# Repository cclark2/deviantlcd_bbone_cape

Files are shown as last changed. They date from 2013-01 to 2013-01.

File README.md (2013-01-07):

DeviantLCD BeagleBone Cape
==========================

Stick it to standards and bit-bang an LCD interface! This cape features a 240x320 LCD with touchscreen connected to the BeagleBone PRU and GPIOs. Use it when you can't spare the BeagleBone's LCD interface pins for a regular display cape.

Special thanks to <a href="http://www.sparkfun.com/">SparkFun</a> for use of their open-source EAGLE libraries.

## Project Links
- <a href="http://www.hitchhikeree.org/beaglebone_capes/deviantlcd/">HitchhikerEE page</a>
- <a href="http://www.youtube.com/watch?v=hFeXr79dWaM">YouTube video</a>
- <a href="https://docs.google.com/folder/d/0B5HjtPsFD8u5RnRneGhOc2xUcGM/edit">Design files on Google Drive</a>
- <a href="http://beagleboard.org/CapeContest/entries/DeviantLCD/">BeagleBone Cape Contest page</a>

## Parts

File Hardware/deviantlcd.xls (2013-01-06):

Qty | Value | Device | Package | Parts | Description | MPN | Price | Total
1 |  | CAT24C256 | SOIC8 | U$1 |  | CAT24C256WI-GT3 | $0.65 | $0.65
1 |  | FE05-2 | FE05-2 | P6 | FEMALE HEADER | TSHC-105-D-03-255-GT-LF | 0.26 | 0.26
1 |  | FE13-2 | FE13-2 | SV1 | FEMALE HEADER | NPTC132KFMS-RC | 2.76 | 2.76
2 |  | FE23-2 | FE23-2 | P8, P9 | FEMALE HEADER | TSHC-123-D-03-255-GT-LF | 0.97 | 1.94
3 |  | HOLE | HOLE | H1, H3, H4 |  |  |  | 0
1 |  | LP3985 | SOT23-5 | U$10 |  | LP3985IM5-2.8/NOPB | 0.38 | 0.38
1 |  | NHD-2.4-240320SF-CTXI | NHD-2.4-240320SF-CTXI | U$4 |  | NHD-2.4-240320SF-CTXI#-T1 | 22.08 | 22.08
2 |  | SN74LVC1T45 | SOT23-6 | U$7, U$8 |  | SN74LVC1T45DBVR | 0.53 | 1.06
1 |  | SN74LVCH16T245 | TSSOP48 | U$3 |  | SN74LVCH16T245DGGR | 2.16 | 2.16
4 | 0 | R-US_R0402 | R0402 | R44, R49, R50, R51 | RESISTOR, American symbol | ERJ-2GE0R00X | 0.07 | 0.28
4 | 0,DNI | R-US_R0402 | R0402 | R43, R52, R53, R54 | RESISTOR, American symbol | ERJ-2GE0R00X | 0.07 | 0.28
10 | 0.1u | C-EUC0603 | C0603 | C1, C2, C3, C4, C5, C7, C8, C9, C10, C11 | CAPACITOR, European symbol | VJ0603V104ZXXCW1BC | 0.06 | 0.6
1 | 10K | R-US_R0402 | R0402 | R42 | RESISTOR, American symbol | WR06X1002FTL | 0.02 | 0.02
1 | 10K | R-US_R0603 | R0603 | R9 | RESISTOR, American symbol | WR06X1002FTL | 0.02 | 0.02
1 | 10n | C-EUC0603 | C0603 | C18 | CAPACITOR, European symbol | VJ0603Y103KXACW1BC | 0.06 | 0.06
1 | 10u | C-EUC0603 | C0603 | C6 | CAPACITOR, European symbol | LMK107BBJ106MALT | 0.64 | 0.64
5 | 150 | R-US_R0603 | R0603 | R33, R45, R46, R47, R48 | RESISTOR, American symbol | 302-150-RC | 0.04 | 0.2
2 | 1u | C-EUC0603 | C0603 | C17, C19 | CAPACITOR, European symbol | C1608X7R1C105K | 0.07 | 0.14
1 | 219-02 | 219-02 | CTS-219-02 | S1 | Surface Mount DIP Switch Series 219 SMT | 219-2MST | 0.58 | 0.58
30 | 33 | R-US_R0402 | R0402 | R8, R10, R11, R12, R13, R15, R16, R17, R18, R19, R21, R22, R23, R24, R26, R27, R28, R29, R30, R32, R35, R36, R37, R38, R39, R40, R41, R56, R57, R58 | RESISTOR, American symbol | CR0402-JW-330GLF | 0.05 | 1.5
3 | 4.75K | R-US_R0603 | R0603 | R2, R5, R7 | RESISTOR, American symbol | CR0603-FX-4751GLF | 0.04 | 0.12
1 | 4.75K, DNI | R-US_R0603 | R0603 | R4 | RESISTOR, American symbol | CR0603-FX-4751GLF | 0.04 | 0.04
2 | 5.6K, 5% | R-US_R0603 | R0603 | R1, R3 | RESISTOR, American symbol | RK73B1JTTDD562J | 0.06 | 0.12
1 | 50 | R-US_R0603 | R0603 | R34 | RESISTOR, American symbol | 302-49.9-RC | 0.04 | 0.04
1 | TPB2,54 | TPB2,54 | B2,54 | TP1 | Test pad |  |  | 0
1 | blue | LEDCHIPLED_0603 | CHIPLED_0603 | LED1 | LED | HT-193NB-5589 | 0.15 | 0.15
1 | green | LEDCHIPLED_0603 | CHIPLED_0603 | LED2 | LED | LG Q971-KN-1 | 0.1 | 0.1
 |  |  |  |  |  |  |  | $36.18

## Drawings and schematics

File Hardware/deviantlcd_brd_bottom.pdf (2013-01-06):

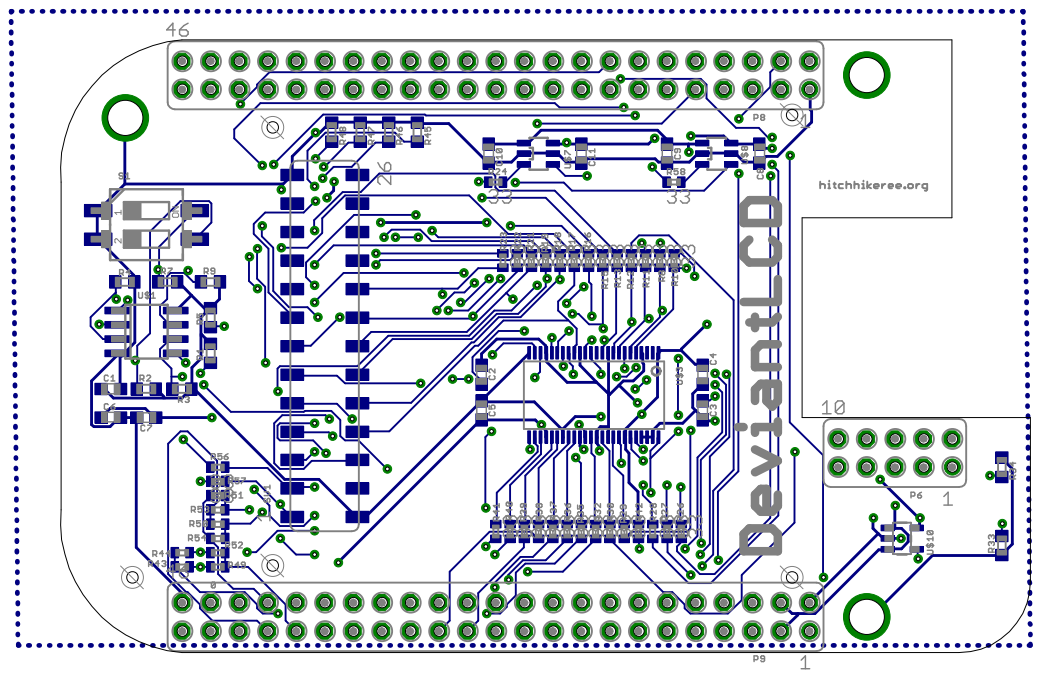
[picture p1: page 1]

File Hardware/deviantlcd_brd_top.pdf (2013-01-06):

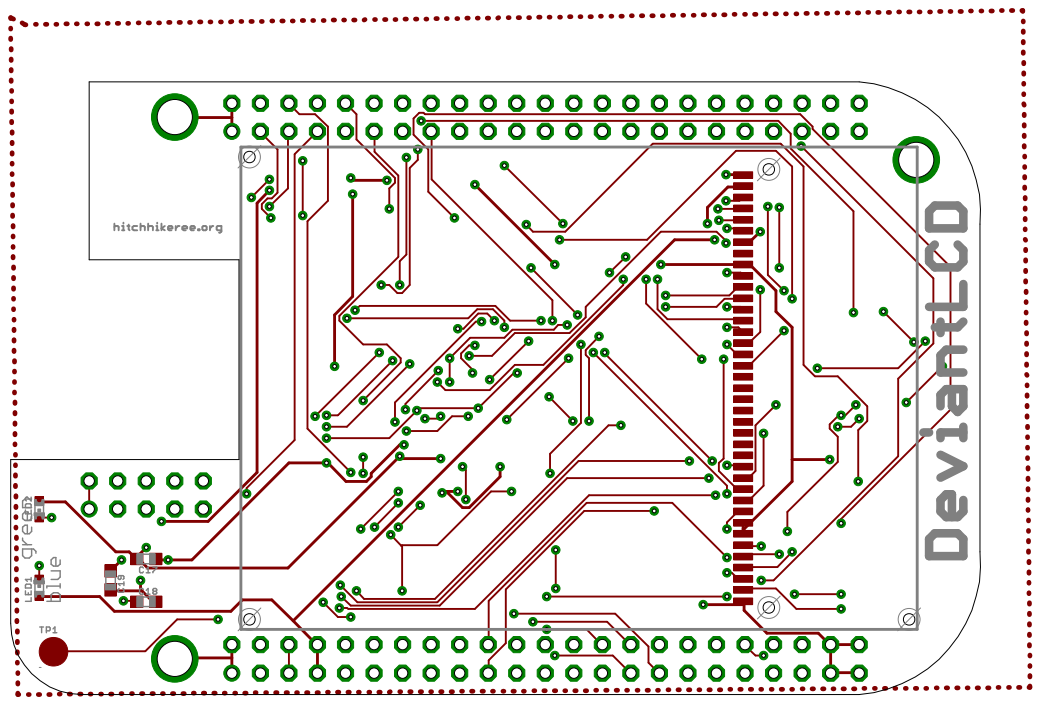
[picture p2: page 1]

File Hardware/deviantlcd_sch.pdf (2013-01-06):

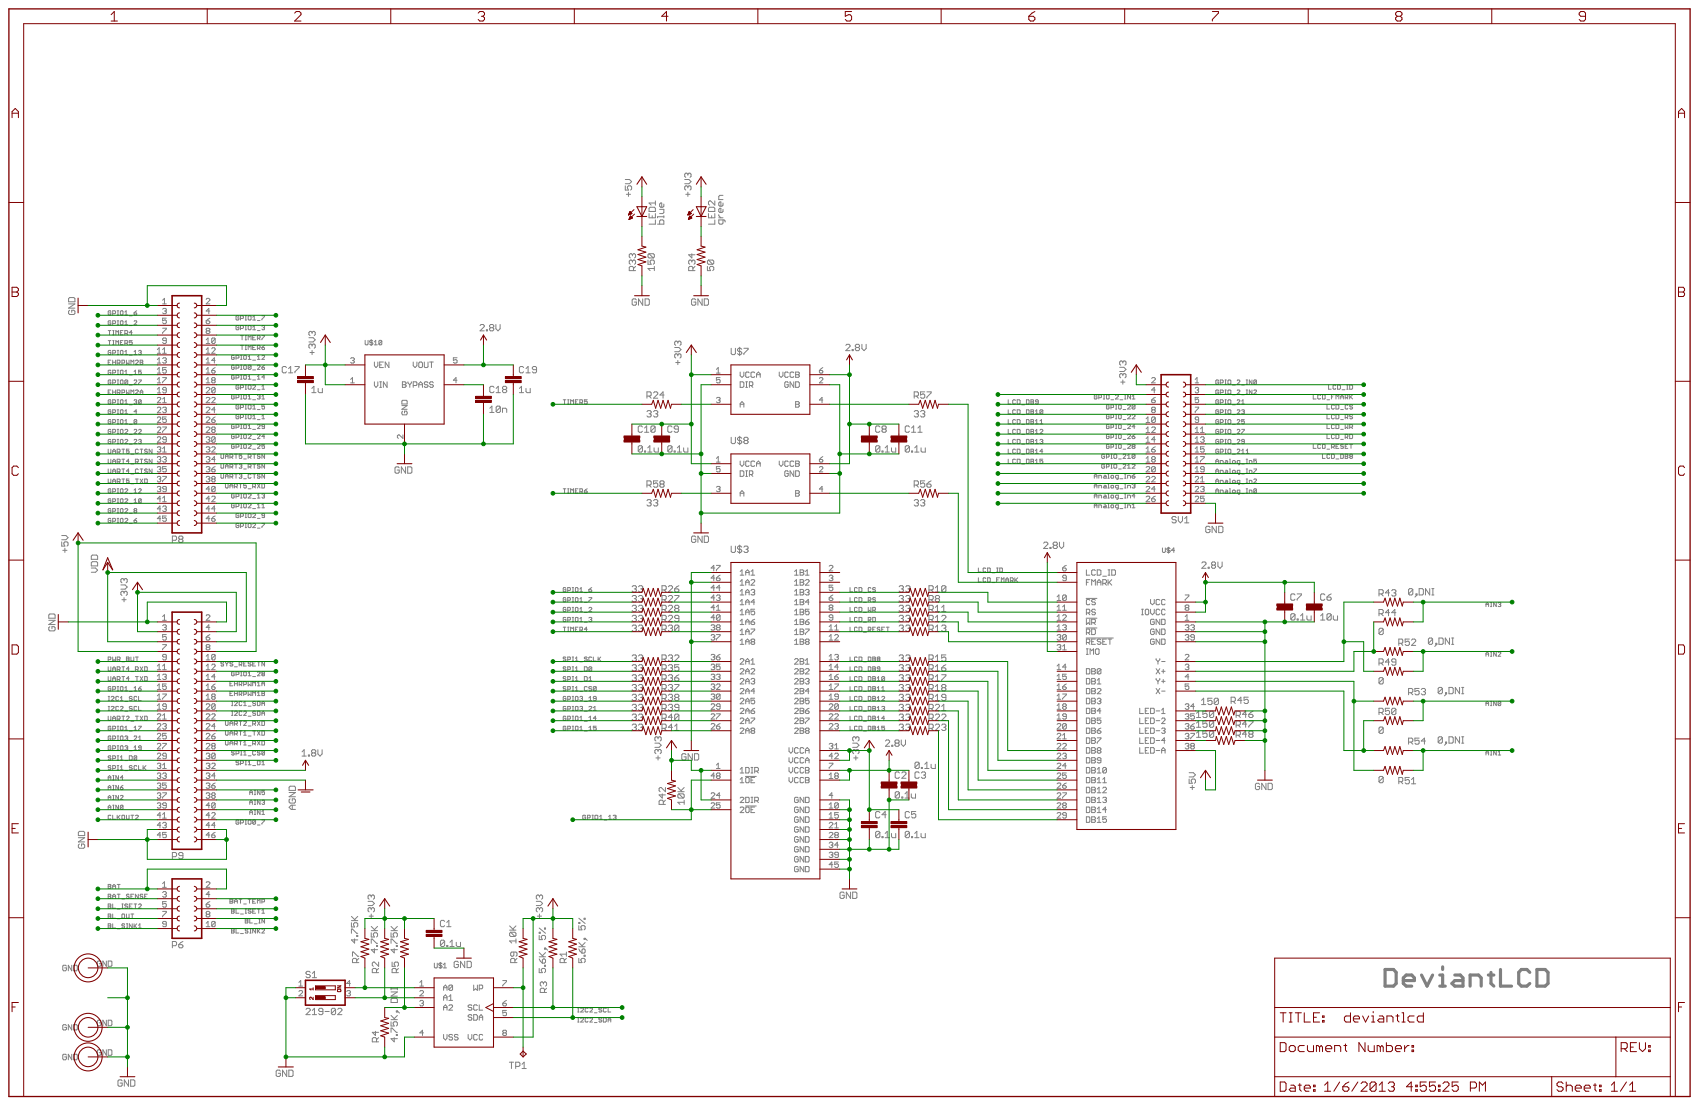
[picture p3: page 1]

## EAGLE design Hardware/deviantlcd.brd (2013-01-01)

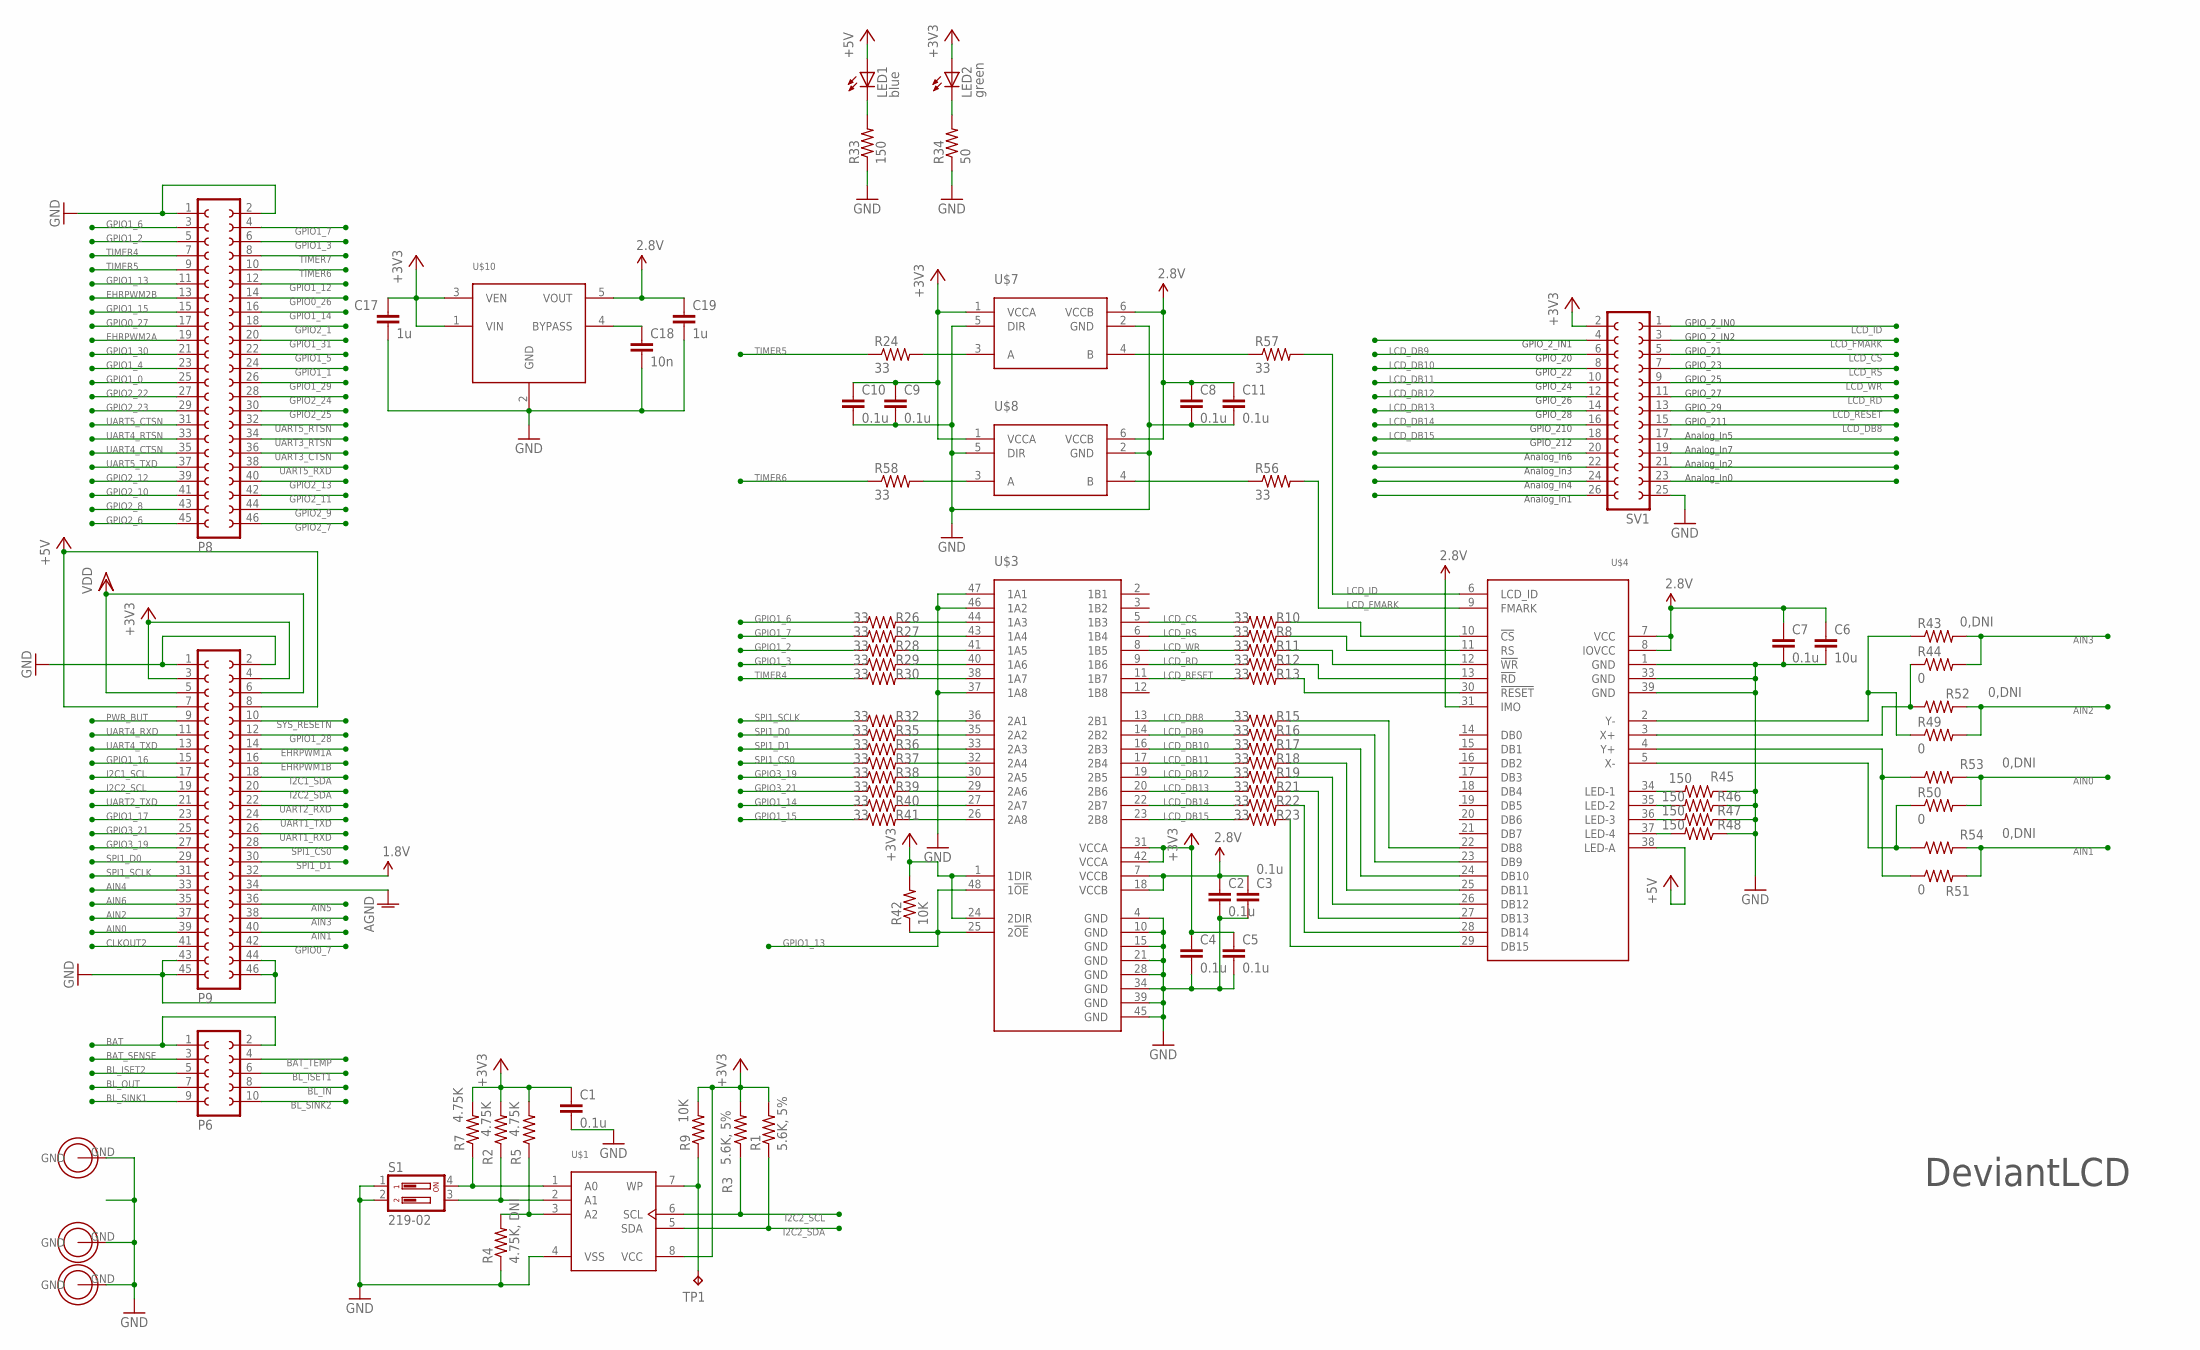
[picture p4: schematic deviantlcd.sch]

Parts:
C1, C2, C3, C4, C5, C7, C8, C9, C10, C11: 0.1u; C0603; MPN VJ0603V104ZXXCW1BC
C6: 10u; C0603; MPN LMK107BBJ106MALT
C17, C19: 1u; C0603; MPN C1608X7R1C105K
C18: 10n; C0603; MPN VJ0603Y103KXACW1BC
H1, H3, H4: HOLE
LED1: blue; CHIPLED_0603; MPN HT-193NB-5589
LED2: green; CHIPLED_0603; MPN LG Q971-KN-1
P6: FE05-2; MPN TSHC-105-D-03-255-GT-LF
P8, P9: FE23-2; MPN TSHC-123-D-03-255-GT-LF
R1, R3: 5.6K, 5%; R0603; MPN RK73B1JTTDD562J
R2, R5, R7: 4.75K; R0603; MPN CR0603-FX-4751GLF
R4: 4.75K, DNI; R0603; MPN CR0603-FX-4751GLF
R8, R10, R11, R12, R13, R15, R16, R17, R18, R19, R21, R22, R23, R24, R26, R27, R29, R30, R32, R35, R36, R37, R38, R39, R40, R41, R56, R57, R58: 33; R0402; MPN CR0402-JW-330GLF
R9: 10K; R0603; MPN WR06X1002FTL
R28: 33; R0402
R33, R45, R46, R47, R48: 150; R0603; MPN 302-150-RC
R34: 50; R0603; MPN 302-49.9-RC
R42: 10K; R0402; MPN WR06X1002FTL
R43, R52, R53, R54: 0,DNI; R0402; MPN ERJ-2GE0R00X
R44, R49, R50, R51: 0; R0402; MPN ERJ-2GE0R00X
S1: 219-02; CTS-219-02; MPN 219-2MST
SV1: FE13-2; MPN NPTC132KFMS-RC
TP1: TPB2,54; B2,54
U$1: CAT24C256; SOIC8; MPN CAT24C256WI-GT3
U$3: SN74LVCH16T245; TSSOP48; MPN SN74LVCH16T245DGGR
U$4: NHD-2.4-240320SF-CTXI; MPN NHD-2.4-240320SF-CTXI#-T1
U$7, U$8: SN74LVC1T45; SOT23-6; MPN SN74LVC1T45DBVR
U$10: LP3985; SOT23-5; MPN LP3985IM5-2.8/NOPB

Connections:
1.8V: P9.32
2.85V: C6.1, C7.1, C8.1, C11.1, C19.1, U$4.7 (VCC), U$4.8 (IOVCC), U$4.31 (IMO), U$7.6 (VCCB), U$8.6 (VCCB), U$10.5 (VOUT)
+3V3: C1.1, C4.1, C5.1, C9.1, C10.1, C17.1, LED2.A, P9.3, P9.4, R1.2, R2.2, R3.2, R5.2, R7.2, R9.2, R42.2, SV1.2, U$1.8 (VCC), U$3.1 (1DIR), U$3.24 (2DIR), U$3.31 (VCCA), U$3.42 (VCCA), U$7.1 (VCCA), U$8.1 (VCCA), U$10.1 (VIN), U$10.3 (VEN)
+5V: LED1.A, P9.7, P9.8, U$4.38 (LED-A)
AGND: P9.34
AIN0: P9.39, R50.2, R53.2
AIN1: P9.40, R51.2, R54.2
AIN2: P9.37, R49.2, R52.2
AIN3: P9.38, R43.2, R44.2
AIN4: P9.33
AIN5: P9.36
AIN6: P9.35
BAT: P6.1, P6.2
BAT_SENSE: P6.3
BAT_TEMP: P6.4
BL_IN: P6.8
BL_ISET1: P6.6
BL_ISET2: P6.5
BL_OUT: P6.7
BL_SINK1: P6.9
BL_SINK2: P6.10
CLKOUT2: P9.41
EHRPWM1A: P9.14
EHRPWM1B: P9.16
EHRPWM2A: P8.19
EHRPWM2B: P8.13
FF: SV1.4
GND: C1.2, C2.2, C3.2, C4.2, C5.2, C6.2, C7.2, C8.2, C9.2, C10.2, C11.2, C17.2, C18.2, C19.2, H1.GND, H3.GND, H4.GND, P8.1, P8.2, P9.1, P9.2, P9.43, P9.44, P9.45, P9.46, R4.1, R33.1, R34.1, R45.1, R46.1, R47.1, R48.1, S1.1, S1.2, SV1.25, U$1.4 (VSS), U$3.4 (GND), U$3.10 (GND), U$3.15 (GND), U$3.21 (GND), U$3.28 (GND), U$3.34 (GND), U$3.37 (1A8), U$3.39 (GND), U$3.45 (GND), U$3.46 (1A2), U$3.47 (1A1), U$4.1 (GND), U$4.33 (GND), U$4.39 (GND), U$7.2 (GND), U$7.5 (DIR), U$8.2 (GND), U$8.5 (DIR), U$10.2 (GND)
GPIO0_7: P9.42
GPIO0_26: P8.14
GPIO0_27: P8.17
GPIO1_0: P8.25
GPIO1_1: P8.24
GPIO1_2: P8.5, R28.1
GPIO1_3: P8.6, R29.1
GPIO1_4: P8.23
GPIO1_5: P8.22
GPIO1_6: P8.3, R26.1
GPIO1_7: P8.4, R27.1
GPIO1_12: P8.12
GPIO1_13: P8.11, R42.1, U$3.25 (2!OE), U$3.48 (1!OE)
GPIO1_14: P8.16, R40.1
GPIO1_15: P8.15, R41.1
GPIO1_16: P9.15
GPIO1_17: P9.23
GPIO1_28: P9.12
GPIO1_29: P8.26
GPIO1_30: P8.21
GPIO1_31: P8.20
GPIO2_1: P8.18
GPIO2_6: P8.45
GPIO2_7: P8.46
GPIO2_8: P8.43
GPIO2_9: P8.44
GPIO2_10: P8.41
GPIO2_11: P8.42
GPIO2_12: P8.39
GPIO2_13: P8.40
GPIO2_22: P8.27
GPIO2_23: P8.29
GPIO2_24: P8.28
GPIO2_25: P8.30
GPIO3_19: P9.27, R38.1
GPIO3_21: P9.25, R39.1
I2C1_SCL: P9.17
I2C1_SDA: P9.18
I2C2_SCL: P9.19, R3.1, U$1.6 (SCL)
I2C2_SDA: P9.20, R1.1, U$1.5 (SDA)
LCD_CS: R10.1, SV1.5, U$3.5 (1B3)
LCD_DB8: R15.1, SV1.15, U$3.13 (2B1)
LCD_DB9: R16.1, SV1.6, U$3.14 (2B2)
LCD_DB10: R17.1, SV1.8, U$3.16 (2B3)
LCD_DB11: R18.1, SV1.10, U$3.17 (2B4)
LCD_DB12: R19.1, SV1.12, U$3.19 (2B5)
LCD_DB13: R21.1, SV1.14, U$3.20 (2B6)
LCD_DB14: R22.1, SV1.16, U$3.22 (2B7)
LCD_DB15: R23.1, SV1.18, U$3.23 (2B8)
LCD_FMARK: R56.2, SV1.3, U$4.9 (FMARK)
LCD_ID: R57.2, SV1.1, U$4.6 (LCD_ID)
LCD_RD: R12.1, SV1.11, U$3.9 (1B6)
LCD_RESET: R13.1, SV1.13, U$3.11 (1B7)
LCD_RS: R8.1, SV1.7, U$3.6 (1B4)
LCD_WR: R11.1, SV1.9, U$3.8 (1B5)
unnamed: R7.1, S1.4, U$1.1 (A0)
unnamed: R2.1, S1.3, U$1.2 (A1)
unnamed: R4.2, R5.1, U$1.3 (A2)
unnamed: R9.1, TP1.TP, U$1.7 (WP)
unnamed: LED1.C, R33.2
unnamed: LED2.C, R34.2
unnamed: R24.2, U$7.3 (A)
unnamed: R58.2, U$8.3 (A)
unnamed: R26.2, U$3.44 (1A3)
unnamed: R27.2, U$3.43 (1A4)
unnamed: R28.2, U$3.41 (1A5)
unnamed: R29.2, U$3.40 (1A6)
unnamed: R30.2, U$3.38 (1A7)
unnamed: R32.2, U$3.36 (2A1)
unnamed: R35.2, U$3.35 (2A2)
unnamed: R36.2, U$3.33 (2A3)
unnamed: R37.2, U$3.32 (2A4)
unnamed: R38.2, U$3.30 (2A5)
unnamed: R39.2, U$3.29 (2A6)
unnamed: R40.2, U$3.27 (2A7)
unnamed: R41.2, U$3.26 (2A8)
unnamed: R57.1, U$7.4 (B)
unnamed: R56.1, U$8.4 (B)
unnamed: R10.2, U$4.10 (!CS)
unnamed: R8.2, U$4.11 (RS)
unnamed: R11.2, U$4.12 (!WR)
unnamed: R12.2, U$4.13 (!RD)
unnamed: R13.2, U$4.30 (!RESET)
unnamed: R23.2, U$4.29 (DB15)
unnamed: R22.2, U$4.28 (DB14)
unnamed: R21.2, U$4.27 (DB13)
unnamed: R19.2, U$4.26 (DB12)
unnamed: R18.2, U$4.25 (DB11)
unnamed: R17.2, U$4.24 (DB10)
unnamed: R16.2, U$4.23 (DB9)
unnamed: R15.2, U$4.22 (DB8)
unnamed: C18.1, U$10.4 (BYPASS)
unnamed: R45.2, U$4.34 (LED-1)
unnamed: R46.2, U$4.35 (LED-2)
unnamed: R47.2, U$4.36 (LED-3)
unnamed: R48.2, U$4.37 (LED-4)
unnamed: R43.1, R49.1, U$4.2 (Y-)
unnamed: R44.1, R52.1, U$4.3 (X+)
unnamed: R51.1, R53.1, U$4.4 (Y+)
unnamed: R50.1, R54.1, U$4.5 (X-)
PWR_BUT: P9.9
SPI1_CS0: P9.28, R37.1
SPI1_D0: P9.29, R35.1
SPI1_D1: P9.30, R36.1
SPI1_SCLK: P9.31, R32.1
SYS_RESETN: P9.10
TIMER4: P8.7, R30.1
TIMER5: P8.9, R24.1
TIMER6: P8.10, R58.1
TIMER7: P8.8
UART1_RXD: P9.26
UART1_TXD: P9.24
UART2_RXD: P9.22
UART2_TXD: P9.21
UART3_CTSN: P8.36
UART3_RTSN: P8.34
UART4_CTSN: P8.35
UART4_RTSN: P8.33
UART4_RXD: P9.11
UART4_TXD: P9.13
UART5_CTSN: P8.31
UART5_RTSN: P8.32
UART5_RXD: P8.38
UART5_TXD: P8.37
VCCB@2: C2.1, C3.1, U$3.7 (VCCB), U$3.18 (VCCB)
VDD: P9.5, P9.6

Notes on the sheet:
DeviantLCD
GPIO_2_IN1
GPIO_20
GPIO_22
GPIO_24
GPIO_26
GPIO_28
GPIO_210
GPIO_212
Analog_In6
Analog_In3
Analog_In4
Analog_In1
GPIO_2_IN0
GPIO_2_IN2
GPIO_21
GPIO_23
GPIO_25
GPIO_27
GPIO_29
GPIO_211
Analog_In5
Analog_In7
Analog_In2
Analog_In0

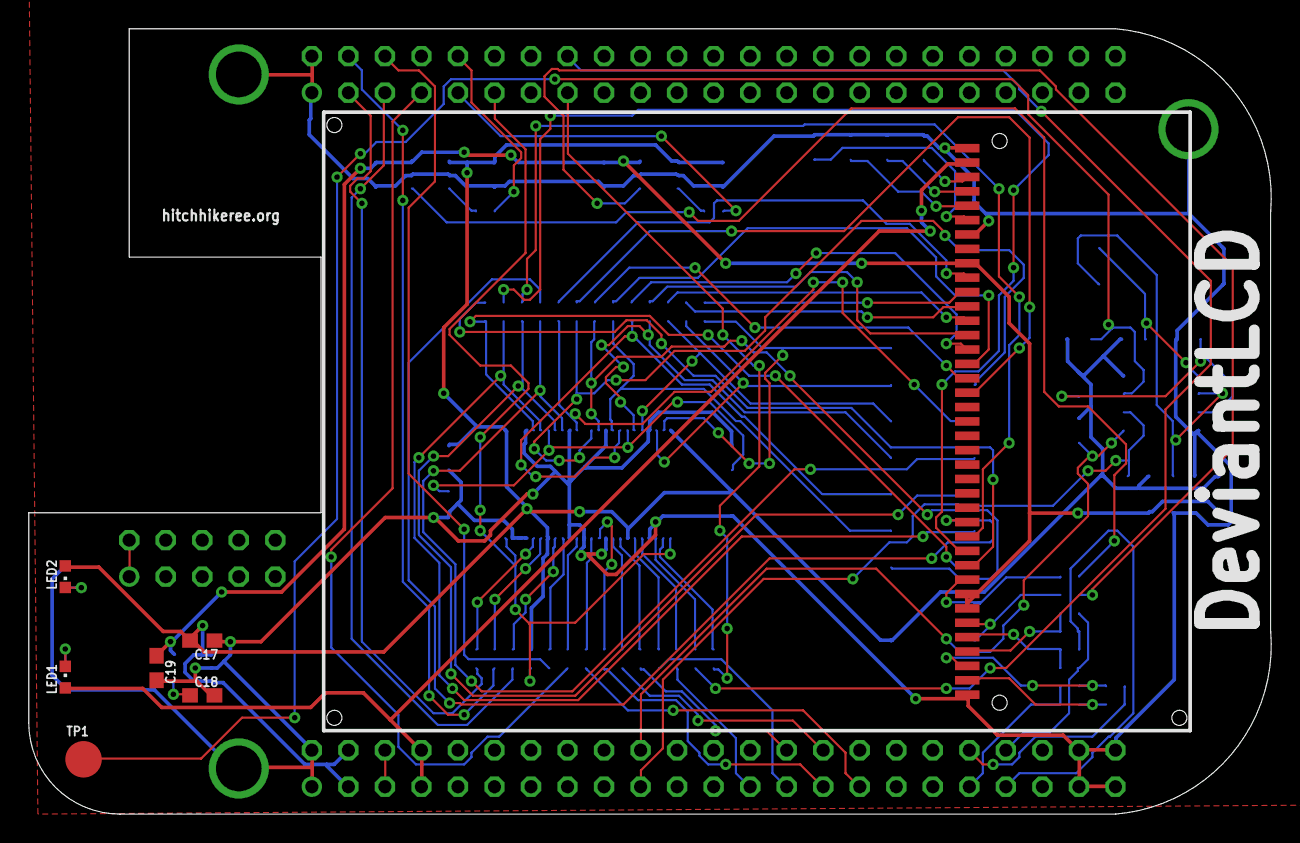
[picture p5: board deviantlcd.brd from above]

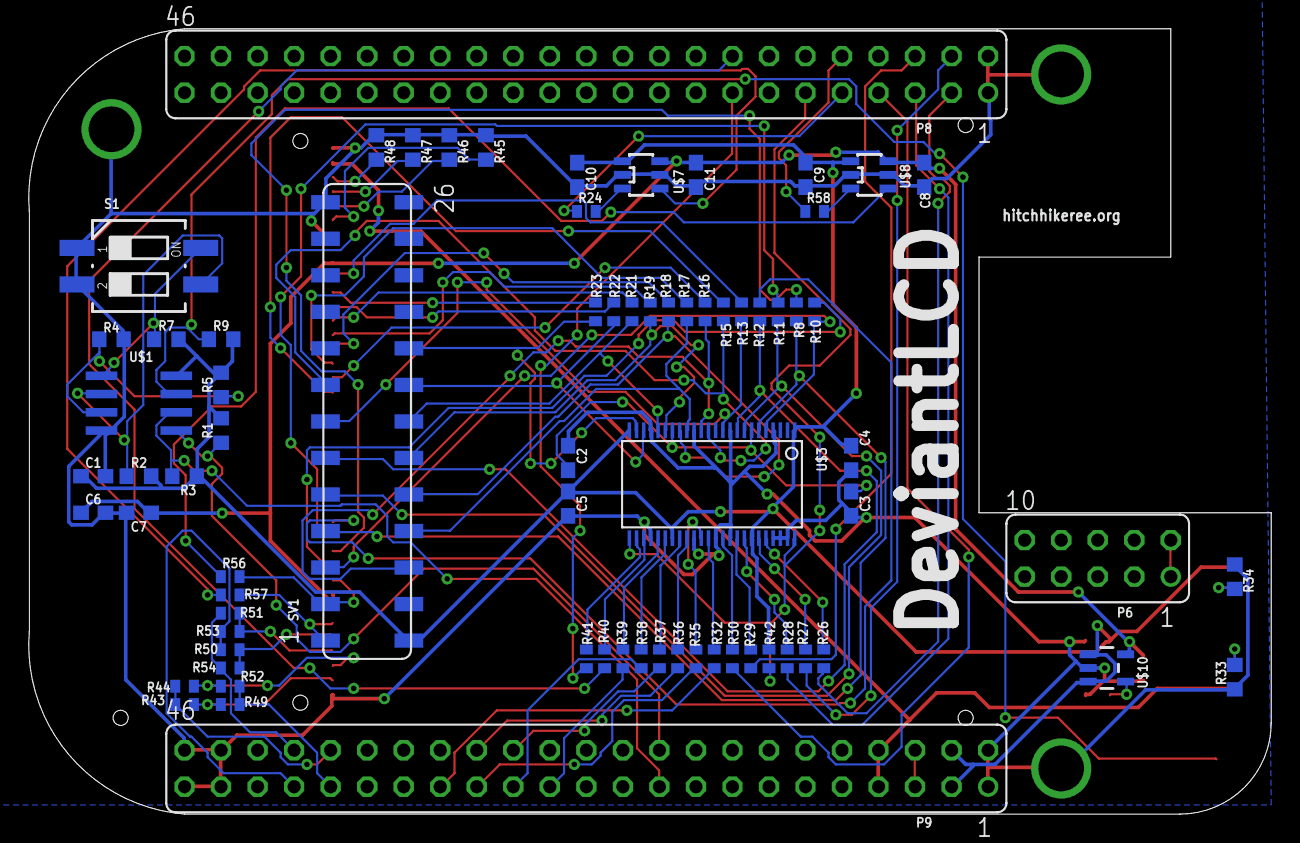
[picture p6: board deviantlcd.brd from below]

Board: 2 copper layers, 86.4 x 54.6 mm, 83 parts (73 on the bottom side), 89 nets.

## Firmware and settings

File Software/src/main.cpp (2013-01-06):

//
//      nunchuck.c
//

#ifndef PORT
//#define PORT "/dev/i2c-1"    // reserved for capes and requiring pullup resistors
#define PORT "/dev/i2c-3"      // p9:pin19=SCL, p9:pin20:SDA
#endif


// 303 accelerometer
#define ADDR_ACCEL_303  0x19            // wii nunchuck address: 0x52
// 303 magnetometer
#define ADDR_MAG_303  0x1e            // wii nunchuck address: 0x52
// 330 accelerometer
#define ADDR_ACCEL_330  0x18            // wii nunchuck address: 0x52
// 330 gyroscope
#define ADDR_GYRO_330  0x6b            // wii nunchuck address: 0x52

// camera
#define ADDR_CAM  0x3C            // wii nunchuck address: 0x52


#include <stdio.h>
#include <fcntl.h>
#include <stdlib.h>
#include <linux/i2c-dev.h>
#include <sys/ioctl.h>
#include <unistd.h>
#include <sys/mman.h>
#include <errno.h>
#include <string.h>
#include <stdint.h>

#include <iostream>
#include <fstream>
#include <iomanip>
#include <stdexcept>
#include <sstream>

#include <prussdrv.h>
#include <pruss_intc_mapping.h>
#include <opencv2/opencv.hpp>
#include <opencv2/core/core.hpp>
#include <opencv2/highgui/highgui.hpp>

#include "mem_map.h"

#define error(x...) { fprintf(stderr, "\nE%d: ", __LINE__); fprintf(stderr, x); fprintf(stderr, "\n\n"); exit(1); }

#define DDR_BASEADDR 0x80000000
#define OFFSET_DDR	 (224*1024*1024)
#define PRU_DDR_SIZE (16*1024*1024)
#define PRU0_DDR    ( DDR_BASEADDR + OFFSET_DDR )
#define PRU1_DDR    ( PRU0_DDR +PRU_DDR_SIZE)


int main()
{
  // gpio 2.3 (timer7) = lcd data gate = 67 (gpmc_oen_ren)
  // gpio 1.6 = lcd cs = 38 (gpmc_ad6)
  // gpio 1.7 = lcd rs = 39 (gpmc_ad7)
  // gpio 1.2 = lcd wr = 34 (gpmc_ad2)
  // gpio 1.28 = lcd rd = 60 (gpmc_ben1)
  // gpio 2.2 (timer4) lcd reset 66 (gpmc_advn_ale)
  
  // gpio 3.14 (spi1_sclk) = lcd db8 = pru0.0 = 110 (mcasp0_aclkx)
  // gpio 3.15 (spi1_d0) = lcd db9 = pru0.1 = 111 (mcasp0_fsx)
  // gpio 3.16 (spi1_d1) = lcd db10 = pru0.2 = 112 (mcasp0_axr0)
  // gpio 3.17 (spi1_cs0) = lcd db11 = pru0.3 = 113 (mcasp0_ahclkr)
  // gpio 3.19 = lcd db12 = pru0.5 =115 (mcasp0_fsr)
  // gpio 3.21 = lcd db13 = pru0.7 = 117 (mcasp0_ahclkx)
  // gpio 1.12 = lcd db14 = pru0.14 = 44 (gpmc_ad12)
  // gpio 1.13 = lcd db15 = pru0.15 = 45 (gpmc_ad13)
  
  system( "echo 67 > /sys/class/gpio/unexport" );
  system( "echo 38 > /sys/class/gpio/unexport" );
  system( "echo 39 > /sys/class/gpio/unexport" );
  system( "echo 34 > /sys/class/gpio/unexport" );
  system( "echo 60 > /sys/class/gpio/unexport" );
  system( "echo 66 > /sys/class/gpio/unexport" );
  
  if( 0 != system( "echo 07 > /sys/kernel/debug/omap_mux/gpmc_oen_ren" ) )
    throw std::runtime_error( "Failed to set mux for lcd data gate" );
  if( 0 != system( "echo 07 > /sys/kernel/debug/omap_mux/gpmc_ad6" ) )
    throw std::runtime_error( "Failed to set mux for lcd cs" );
  if( 0 != system( "echo 07 > /sys/kernel/debug/omap_mux/gpmc_ad7" ) )
    throw std::runtime_error( "Failed to set mux for lcd rs" );
  if( 0 != system( "echo 07 > /sys/kernel/debug/omap_mux/gpmc_ad2" ) )
    throw std::runtime_error( "Failed to set mux for lcd wr" );
  if( 0 != system( "echo 07 > /sys/kernel/debug/omap_mux/gpmc_ben1" ) )
    throw std::runtime_error( "Failed to set mux for lcd rd" );
  if( 0 != system( "echo 07 > /sys/kernel/debug/omap_mux/gpmc_advn_ale" ) )
    throw std::runtime_error( "Failed to set mux for lcd reset" );
  
  if( 0 != system( "echo 67 > /sys/class/gpio/export" ) )
    throw std::runtime_error( "Failed to export lcd data gate" );
  if( 0 != system( "echo 38 > /sys/class/gpio/export" ) )
    throw std::runtime_error( "Failed to export lcd cs" );
  if( 0 != system( "echo 39 > /sys/class/gpio/export" ) )
    throw std::runtime_error( "Failed to export lcd rs" );
  if( 0 != system( "echo 34 > /sys/class/gpio/export" ) )
    throw std::runtime_error( "Failed to export lcd wr" );
  if( 0 != system( "echo 60 > /sys/class/gpio/export" ) )
    throw std::runtime_error( "Failed to export lcd rd" );
  if( 0 != system( "echo 66 > /sys/class/gpio/export" ) )
    throw std::runtime_error( "Failed to export lcd reset" );
    
  if( 0 != system( "echo out > /sys/class/gpio/gpio67/direction" ) )
    throw std::runtime_error( "Failed to set lcd data gate gpio direction" );
  if( 0 != system( "echo out > /sys/class/gpio/gpio38/direction" ) )
    throw std::runtime_error( "Failed to set lcd cs gpio direction" );
  if( 0 != system( "echo out > /sys/class/gpio/gpio39/direction" ) )
    throw std::runtime_error( "Failed to set lcd rs gpio direction" );
  if( 0 != system( "echo out > /sys/class/gpio/gpio34/direction" ) )
    throw std::runtime_error( "Failed to set lcd wr gpio direction" );
  if( 0 != system( "echo out > /sys/class/gpio/gpio60/direction" ) )
    throw std::runtime_error( "Failed to set lcd rd gpio direction" );
  if( 0 != system( "echo out > /sys/class/gpio/gpio66/direction" ) )
    throw std::runtime_error( "Failed to set lcd reset gpio direction" );
    
  if( 0 != system( "echo 05 > /sys/kernel/debug/omap_mux/mcasp0_aclkx" ) )
    throw std::runtime_error( "Failed to set mux for lcd db8" );
  if( 0 != system( "echo 05 > /sys/kernel/debug/omap_mux/mcasp0_fsx" ) )
    throw std::runtime_error( "Failed to set mux for lcd db9" );
  if( 0 != system( "echo 05 > /sys/kernel/debug/omap_mux/mcasp0_axr0" ) )
    throw std::runtime_error( "Failed to set mux for lcd db10" );
  if( 0 != system( "echo 05 > /sys/kernel/debug/omap_mux/mcasp0_ahclkr" ) )
    throw std::runtime_error( "Failed to set mux for lcd db11" );
  if( 0 != system( "echo 05 > /sys/kernel/debug/omap_mux/mcasp0_fsr" ) )
    throw std::runtime_error( "Failed to set mux for lcd db12" );
  if( 0 != system( "echo 05 > /sys/kernel/debug/omap_mux/mcasp0_ahclkx" ) )
    throw std::runtime_error( "Failed to set mux for lcd db13" );
  if( 0 != system( "echo 06 > /sys/kernel/debug/omap_mux/gpmc_ad12" ) )
    throw std::runtime_error( "Failed to set mux for lcd db14" );
  if( 0 != system( "echo 06 > /sys/kernel/debug/omap_mux/gpmc_ad13" ) )
    throw std::runtime_error( "Failed to set mux for lcd db15" );
  
  
  
  std::ofstream lcd_pru_gate( "/sys/class/gpio/gpio67/value" );
  std::ofstream lcd_pru_cs( "/sys/class/gpio/gpio38/value" );
  std::ofstream lcd_pru_rs( "/sys/class/gpio/gpio39/value" );
  std::ofstream lcd_pru_wr( "/sys/class/gpio/gpio34/value" );
  std::ofstream lcd_pru_rd( "/sys/class/gpio/gpio60/value" );
  std::ofstream lcd_pru_reset( "/sys/class/gpio/gpio66/value" );
  
  if( !lcd_pru_gate.is_open() || !lcd_pru_cs.is_open() || !lcd_pru_rs.is_open() || !lcd_pru_wr.is_open()
      || !lcd_pru_rd.is_open() || !lcd_pru_reset.is_open()  )
    throw std::runtime_error( "Failed to open lcd pru gpios" );

 
  lcd_pru_cs << '1' << std::endl;
  lcd_pru_rs << '1' << std::endl;
  lcd_pru_wr << '1' << std::endl;
  lcd_pru_rd << '1' << std::endl;
  lcd_pru_gate << '0' << std::endl;
  lcd_pru_reset << '0' << std::endl;
  usleep( 100000 );
  lcd_pru_reset << '1' << std::endl;

  
  
  
  
  
  
  // gpio 0.22 (ehrpwm2a) = lcd cs = 22 (gpmc_ad8)
  // gpio 0.23 (ehrpwm2b) = lcd rs = 23 (gpmc_ad9)
  // gpio 0.30 (uart4_rxd) = lcd wr = 30 (gpmc_wait0)
  // gpio 1.1 = lcd rd = 33 (gpmc_ad1)
  // gpio 0.26 = lcd reset = 26 (gpmc_ad10)
  // gpio 0.2 (uart2_rxd) = lcd db8 = 2 (spi0_sclk)
  // gpio 0.3 (uart2_txd) = lcd db9 = 3 (spi0_d0)
  // gpio 0.4 (i2c1_sda) = lcd db10 = 4 (spi0_d1)
  // gpio 0.5 (i2c1_scl) = lcd db11 = 5 (spi0_cs0)
  // gpio 0.8 (uart4_ctsn) = lcd db12 = 8 (lcd_data12)
  // gpio 0.9 (uart4_rtsn) = lcd db13 = 9 (lcd_data13)
  // gpio 0.10 (uart5_ctsn) = lcd db14 = 10 (lcd_data14)
  // gpio 0.11 (uart5_rtsn) = lcd db15 = 11 (lcd_data15)
 
  system( "echo 22 > /sys/class/gpio/unexport" );
  system( "echo 23 > /sys/class/gpio/unexport" );
  system( "echo 30 > /sys/class/gpio/unexport" );
  system( "echo 33 > /sys/class/gpio/unexport" );
  system( "echo 26 > /sys/class/gpio/unexport" );
  system( "echo 2 > /sys/class/gpio/unexport" );
  system( "echo 3 > /sys/class/gpio/unexport" );
  system( "echo 4 > /sys/class/gpio/unexport" );
  system( "echo 5 > /sys/class/gpio/unexport" );
  system( "echo 8 > /sys/class/gpio/unexport" );
  system( "echo 9 > /sys/class/gpio/unexport" );
  system( "echo 10 > /sys/class/gpio/unexport" );
  system( "echo 11 > /sys/class/gpio/unexport" );
  
  if( 0 != system( "echo 07 > /sys/kernel/debug/omap_mux/gpmc_ad8" ) )
    throw std::runtime_error( "Failed to set mux for lcd cs" );
  if( 0 != system( "echo 07 > /sys/kernel/debug/omap_mux/gpmc_ad9" ) )
    throw std::runtime_error( "Failed to set mux for lcd rs" );
  if( 0 != system( "echo 07 > /sys/kernel/debug/omap_mux/gpmc_wait0" ) )
    throw std::runtime_error( "Failed to set mux for lcd wr" );
  if( 0 != system( "echo 07 > /sys/kernel/debug/omap_mux/gpmc_ad1" ) )
    throw std::runtime_error( "Failed to set mux for lcd rd" );
  if( 0 != system( "echo 07 > /sys/kernel/debug/omap_mux/gpmc_ad10" ) )
    throw std::runtime_error( "Failed to set mux for lcd reset" );
  if( 0 != system( "echo 07 > /sys/kernel/debug/omap_mux/spi0_sclk" ) )
    throw std::runtime_error( "Failed to set mux for lcd db8" );
  if( 0 != system( "echo 07 > /sys/kernel/debug/omap_mux/spi0_d0" ) )
    throw std::runtime_error( "Failed to set mux for lcd db9" );
  if( 0 != system( "echo 07 > /sys/kernel/debug/omap_mux/spi0_d1" ) )
    throw std::runtime_error( "Failed to set mux for lcd db10" );
  if( 0 != system( "echo 07 > /sys/kernel/debug/omap_mux/spi0_cs0" ) )
    throw std::runtime_error( "Failed to set mux for lcd db11" );
  if( 0 != system( "echo 07 > /sys/kernel/debug/omap_mux/lcd_data12" ) )
    throw std::runtime_error( "Failed to set mux for lcd db12" );
  if( 0 != system( "echo 07 > /sys/kernel/debug/omap_mux/lcd_data13" ) )
    throw std::runtime_error( "Failed to set mux for lcd db13" );
  if( 0 != system( "echo 07 > /sys/kernel/debug/omap_mux/lcd_data14" ) )
    throw std::runtime_error( "Failed to set mux for lcd db14" );
  if( 0 != system( "echo 07 > /sys/kernel/debug/omap_mux/lcd_data15" ) )
    throw std::runtime_error( "Failed to set mux for lcd db15" );
    
  if( 0 != system( "echo 22 > /sys/class/gpio/export" ) )
    throw std::runtime_error( "Failed to export lcd cs" );
  if( 0 != system( "echo 23 > /sys/class/gpio/export" ) )
    throw std::runtime_error( "Failed to export lcd rs" );
  if( 0 != system( "echo 30 > /sys/class/gpio/export" ) )
    throw std::runtime_error( "Failed to export lcd wr" );
  if( 0 != system( "echo 33 > /sys/class/gpio/export" ) )
    throw std::runtime_error( "Failed to export lcd rd" );
  if( 0 != system( "echo 26 > /sys/class/gpio/export" ) )
    throw std::runtime_error( "Failed to export lcd reset" );
  if( 0 != system( "echo 2 > /sys/class/gpio/export" ) )
    throw std::runtime_error( "Failed to export lcd db8" );
  if( 0 != system( "echo 3 > /sys/class/gpio/export" ) )
    throw std::runtime_error( "Failed to export lcd db9" );
  if( 0 != system( "echo 4 > /sys/class/gpio/export" ) )
    throw std::runtime_error( "Failed to export lcd db10" );
  if( 0 != system( "echo 5 > /sys/class/gpio/export" ) )
    throw std::runtime_error( "Failed to export lcd db11" );
  if( 0 != system( "echo 8 > /sys/class/gpio/export" ) )
    throw std::runtime_error( "Failed to export lcd db12" );
  if( 0 != system( "echo 9 > /sys/class/gpio/export" ) )
    throw std::runtime_error( "Failed to export lcd db13" );
  if( 0 != system( "echo 10 > /sys/class/gpio/export" ) )
    throw std::runtime_error( "Failed to export lcd db14" );
  if( 0 != system( "echo 11 > /sys/class/gpio/export" ) )
    throw std::runtime_error( "Failed to export lcd db15" );
    
  if( 0 != system( "echo out > /sys/class/gpio/gpio22/direction" ) )
    throw std::runtime_error( "Failed to set lcd cs gpio direction" );
  if( 0 != system( "echo out > /sys/class/gpio/gpio23/direction" ) )
    throw std::runtime_error( "Failed to set lcd rs gpio direction" );
  if( 0 != system( "echo out > /sys/class/gpio/gpio30/direction" ) )
    throw std::runtime_error( "Failed to set lcd wr gpio direction" );
  if( 0 != system( "echo out > /sys/class/gpio/gpio33/direction" ) )
    throw std::runtime_error( "Failed to set lcd rd gpio direction" );
  if( 0 != system( "echo out > /sys/class/gpio/gpio26/direction" ) )
    throw std::runtime_error( "Failed to set lcd reset gpio direction" );
  if( 0 != system( "echo out > /sys/class/gpio/gpio2/direction" ) )
    throw std::runtime_error( "Failed to set lcd db8 gpio direction" );
  if( 0 != system( "echo out > /sys/class/gpio/gpio3/direction" ) )
    throw std::runtime_error( "Failed to set lcd db9 gpio direction" );
  if( 0 != system( "echo out > /sys/class/gpio/gpio4/direction" ) )
    throw std::runtime_error( "Failed to set lcd db10 gpio direction" );
  if( 0 != system( "echo out > /sys/class/gpio/gpio5/direction" ) )
    throw std::runtime_error( "Failed to set lcd db11 gpio direction" );
  if( 0 != system( "echo out > /sys/class/gpio/gpio8/direction" ) )
    throw std::runtime_error( "Failed to set lcd db12 gpio direction" );
  if( 0 != system( "echo out > /sys/class/gpio/gpio9/direction" ) )
    throw std::runtime_error( "Failed to set lcd db13 gpio direction" );
  if( 0 != system( "echo out > /sys/class/gpio/gpio10/direction" ) )
    throw std::runtime_error( "Failed to set lcd db14 gpio direction" );
  if( 0 != system( "echo out > /sys/class/gpio/gpio11/direction" ) )
    throw std::runtime_error( "Failed to set lcd db15 gpio direction" );
    

    
    
    
  std::ofstream lcd_cs( "/sys/class/gpio/gpio22/value" );
  std::ofstream lcd_rs( "/sys/class/gpio/gpio23/value" );
  std::ofstream lcd_wr( "/sys/class/gpio/gpio30/value" );
  std::ofstream lcd_rd( "/sys/class/gpio/gpio33/value" );
  std::ofstream lcd_reset( "/sys/class/gpio/gpio26/value" );
  std::ofstream lcd_db8( "/sys/class/gpio/gpio2/value" );
  std::ofstream lcd_db9( "/sys/class/gpio/gpio3/value" );
  std::ofstream lcd_db10( "/sys/class/gpio/gpio4/value" );
  std::ofstream lcd_db11( "/sys/class/gpio/gpio5/value" );
  std::ofstream lcd_db12( "/sys/class/gpio/gpio8/value" );
  std::ofstream lcd_db13( "/sys/class/gpio/gpio9/value" );
  std::ofstream lcd_db14( "/sys/class/gpio/gpio10/value" );
  std::ofstream lcd_db15( "/sys/class/gpio/gpio11/value" );
  
  if( !lcd_cs.is_open() || !lcd_rs.is_open() || !lcd_wr.is_open() || !lcd_rd.is_open() || 
      !lcd_reset.is_open() || !lcd_db8.is_open() || !lcd_db9.is_open() || !lcd_db10.is_open() ||
      !lcd_db11.is_open() || !lcd_db12.is_open() || !lcd_db13.is_open() || !lcd_db14.is_open() ||
      !lcd_db15.is_open() )
    throw std::runtime_error( "Failed to open lcd gpios" );

  lcd_cs << '1' << std::endl;
  lcd_rs << '1' << std::endl;
  lcd_wr << '1' << std::endl;
  lcd_rd << '1' << std::endl;
  lcd_reset << '0' << std::endl;
  usleep( 100000 );
  lcd_reset << '1' << std::endl;
  lcd_db8 << '0' << std::endl;
  lcd_db9 << '0' << std::endl;
  lcd_db10 << '0' << std::endl;
  lcd_db11 << '0' << std::endl;
  lcd_db12 << '0' << std::endl;
  lcd_db13 << '0' << std::endl;
  lcd_db14 << '0' << std::endl;
  lcd_db15 << '0' << std::endl;

  
  

  
  // gpio 2.24 = cam reset = 88 (lcd_pclk)
  // gpio 1.29 = cam led = 61 (gpmc_csn0)
  // gpio 2.5 (timer5) = cam data gate = 69 (gpmc_ben0_cle)

  // gpio 2.6 = cam data 0 = pru1.0 = 70 (lcd_data0)
  // gpio 2.7 = cam data 1 = pru1.1 = 71 (lcd_data1)
  // gpio 2.8 = cam data 2 = pru1.2 = 72 (lcd_data2)
  // gpio 2.9 = cam data 3 = pru1.3 = 73 (lcd_data3)
  // gpio 2.10 = cam data 4 = pru1.4 = 74 (lcd_data4)
  // gpio 2.11 = cam data 5 = pru1.5 = 75 (lcd_data5)
  // gpio 2.12 = cam data 6 = pru1.6 = 76 (lcd_data6)
  // gpio 2.13 = cam data 7 = pru1.7 = 77 (lcd_data7)
  // gpio 2.22 = cam vsync = pru1.8 = 86 (lcd_vsync)
  // gpio 2.23 = cam hsync = pru1.9 = 87 (lcd_hsync)
  // gpio 0.14 (uart1_rxd) = cam clock = pru1.16 = 14 (uart1_rxd)

  system( "echo 88 > /sys/class/gpio/unexport" );
  system( "echo 61 > /sys/class/gpio/unexport" );
  system( "echo 69 > /sys/class/gpio/unexport" );
  

  if( 0 != system( "echo 07 > /sys/kernel/debug/omap_mux/lcd_pclk" ) )
    throw std::runtime_error( "Failed to set mux for cam reset gpio" );
  if( 0 != system( "echo 07 > /sys/kernel/debug/omap_mux/gpmc_csn0" ) )
    throw std::runtime_error( "Failed to set mux for cam led gpio" );
  if( 0 != system( "echo 07 > /sys/kernel/debug/omap_mux/gpmc_ben0_cle" ) )
    throw std::runtime_error( "Failed to set mux for cam data gate gpio" );
    
  if( 0 != system( "echo 88 > /sys/class/gpio/export" ) )
    throw std::runtime_error( "Failed to export cam reset gpio" );
  if( 0 != system( "echo 61 > /sys/class/gpio/export" ) )
    throw std::runtime_error( "Failed to export cam led gpio" );
  if( 0 != system( "echo 69 > /sys/class/gpio/export" ) )
    throw std::runtime_error( "Failed to export cam data gate gpio" );
    
  if( 0 != system( "echo out > /sys/class/gpio/gpio88/direction" ) )
    throw std::runtime_error( "Failed to set cam reset gpio direction" );
  if( 0 != system( "echo out > /sys/class/gpio/gpio61/direction" ) )
    throw std::runtime_error( "Failed to set cam led gpio direction" );
  if( 0 != system( "echo out > /sys/class/gpio/gpio69/direction" ) )
    throw std::runtime_error( "Failed to set cam data gate gpio direction" );
    
  if( 0 != system( "echo 36 > /sys/kernel/debug/omap_mux/lcd_data0" ) )
    throw std::runtime_error( "Failed to set mux for cam data 0 pru" );
  if( 0 != system( "echo 36 > /sys/kernel/debug/omap_mux/lcd_data1" ) )
    throw std::runtime_error( "Failed to set mux for cam data 1 pru" );
  if( 0 != system( "echo 36 > /sys/kernel/debug/omap_mux/lcd_data2" ) )
    throw std::runtime_error( "Failed to set mux for cam data 2 pru" );
  if( 0 != system( "echo 36 > /sys/kernel/debug/omap_mux/lcd_data3" ) )
    throw std::runtime_error( "Failed to set mux for cam data 3 pru" );
  if( 0 != system( "echo 36 > /sys/kernel/debug/omap_mux/lcd_data4" ) )
    throw std::runtime_error( "Failed to set mux for cam data 4 pru" );
  if( 0 != system( "echo 36 > /sys/kernel/debug/omap_mux/lcd_data5" ) )
    throw std::runtime_error( "Failed to set mux for cam data 5 pru" );
  if( 0 != system( "echo 36 > /sys/kernel/debug/omap_mux/lcd_data6" ) )
    throw std::runtime_error( "Failed to set mux for cam data 6 pru" );
  if( 0 != system( "echo 36 > /sys/kernel/debug/omap_mux/lcd_data7" ) )
    throw std::runtime_error( "Failed to set mux for cam data 7 pru" );
  if( 0 != system( "echo 36 > /sys/kernel/debug/omap_mux/lcd_vsync" ) )
    throw std::runtime_error( "Failed to set mux for cam vsync pru" );
  if( 0 != system( "echo 36 > /sys/kernel/debug/omap_mux/lcd_hsync" ) )
    throw std::runtime_error( "Failed to set mux for cam hsync pru" );
  if( 0 != system( "echo 36 > /sys/kernel/debug/omap_mux/uart1_rxd" ) )
    throw std::runtime_error( "Failed to set mux for cam clock pru" );





  std::ofstream cam_reset( "/sys/class/gpio/gpio88/value" );
  std::ofstream cam_led( "/sys/class/gpio/gpio61/value" );
  std::ofstream cam_data( "/sys/class/gpio/gpio69/value" );
  
  if( !cam_reset.is_open() || !cam_led.is_open() || !cam_data.is_open() )
    throw std::runtime_error( "Failed to open cam gpios" );

  cam_reset << '1' << std::endl;
  cam_led << '1' << std::endl;
  cam_data << '0' << std::endl;
  
  
  
  
  
  
  
  
  
  
  
  
  
  
  
  system("modprobe uio_pruss");
 
  unsigned int ret;
  tpruss_intc_initdata pruss_intc_initdata = PRUSS_INTC_INITDATA;
  prussdrv_init ();		

  if( 0 != prussdrv_open(PRU_EVTOUT_0) )
    throw std::runtime_error( "Failed to open pru0" );
  if( 0 != prussdrv_open(PRU_EVTOUT_1) )
    throw std::runtime_error( "Failed to open pru1" );

  prussdrv_pruintc_init(&pruss_intc_initdata);

  volatile uint32_t *pru0_data, *pru1_data, *pru_shared;
  
  prussdrv_map_prumem (PRUSS0_PRU0_DATARAM, (void**)&pru0_data);
  prussdrv_map_prumem (PRUSS0_PRU1_DATARAM, (void**)&pru1_data);
  prussdrv_map_prumem(PRUSS0_SHARED_DATARAM, (void**)&pru_shared);
  
  memset( (void*)pru0_data, 0, 8*1024);
  memset( (void*)pru1_data, 0, 8*1024);
  memset( (void*)pru_shared, 0, 12*1024);

  volatile uint16_t *pru0_ddr, *pru1_ddr;	

  int mem_fd = open("/dev/mem", O_RDWR);
  if (mem_fd < 0)
    throw std::runtime_error( "Failed to open /dev/mem" );

  pru0_ddr= (uint16_t*)mmap(0, PRU_DDR_SIZE, PROT_WRITE | PROT_READ, MAP_SHARED, mem_fd, PRU0_DDR);
  if (pru0_ddr == NULL)
    throw std::runtime_error( "Failed to map pru0 ddr" );
    
  pru1_ddr= (uint16_t*)mmap(0, PRU_DDR_SIZE, PROT_WRITE | PROT_READ, MAP_SHARED, mem_fd, PRU1_DDR);
  if (pru1_ddr == NULL)
    throw std::runtime_error( "Failed to map pru1 ddr" );
    
    
  memset( (void*)pru0_ddr, 0, PRU_DDR_SIZE);
  memset( (void*)pru1_ddr, 0, PRU_DDR_SIZE);
    
    
    
    
    
    
  
  
int i=0, n=0, readcnt=1;
  
  // initialization: open port, ioctl address, send 0x40/0x00 init to nunchuck:
  int fd_accel_303 = open(PORT, O_RDWR);
  if(fd_accel_303<0) error("cant open %s - %m", PORT);
  if(ioctl(fd_accel_303, I2C_SLAVE, ADDR_ACCEL_303) < 0) error("cant ioctl %s:0x%02x - %m", PORT, ADDR_ACCEL_303);
  
  int fd_mag_303 = open(PORT, O_RDWR);
  if(fd_mag_303<0) error("cant open %s - %m", PORT);
  if(ioctl(fd_mag_303, I2C_SLAVE, ADDR_MAG_303) < 0) error("cant ioctl %s:0x%02x - %m", PORT, ADDR_MAG_303);
  
  int fd_accel_330 = open(PORT, O_RDWR);
  if(fd_accel_330<0) error("cant open %s - %m", PORT);
  if(ioctl(fd_accel_330, I2C_SLAVE, ADDR_ACCEL_330) < 0) error("cant ioctl %s:0x%02x - %m", PORT, ADDR_ACCEL_330);
  
  int fd_gyro_330 = open(PORT, O_RDWR);
  if(fd_gyro_330<0) error("cant open %s - %m", PORT);
  if(ioctl(fd_gyro_330, I2C_SLAVE, ADDR_GYRO_330) < 0) error("cant ioctl %s:0x%02x - %m", PORT, ADDR_GYRO_330);
  
  int fd_cam = open(PORT, O_RDWR);
  if(fd_cam<0) error("cant open %s - %m", PORT);
  if(ioctl(fd_cam, I2C_SLAVE, ADDR_CAM) < 0) error("cant ioctl %s:0x%02x - %m", PORT, ADDR_CAM);
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

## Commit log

2013-01-01 Design complete, cleanup needed.
    [deviantlcd.brd, deviantlcd.sch, deviantlcd.xlsx]
2013-01-01 BOM done.
    [deviantlcd.brd, deviantlcd.sch, deviantlcd.xls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]
2013-01-06 Added BOM prices, added PDFs of design, sorted files.
    [deviantlcd.brd, deviantlcd.sch, deviantlcd.xls]
2013-01-06 BOM prices for real this time.
    [deviantlcd.xls]
2013-01-06 Fixing BOM formatting.
    [deviantlcd.xls]
